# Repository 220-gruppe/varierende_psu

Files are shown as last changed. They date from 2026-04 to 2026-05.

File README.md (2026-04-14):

Standalone

This is part of the “Projekt SMPS.”

The project is developed using PlatformIO as the framework.

The standalone folder is specifically intended for testing individual components and ongoing development.

There will also be a main PlatformIO project folder. This folder will contain the fully integrated code for the final solution. Each individual component will be placed in its own file, including the functions and behavior required to handle that element—either independently, in coordination with other modules, or within the main program.

A key design decision is whether modules should be implemented as individual classes (allowing state to be managed and modified) or as function-based implementations without maintaining state.

# Working with Hardware 🛠️
To work with hardware e.g schematics and pcb designs you need git LFS and Kicad

### git lfs 
To install git lfs run
```
git lfs install
```
**This must be run** it prevents committing unlocked files which can cause accidental overwrites
```
git config lfs.locksverify true
```

### Kicad
Install via website
## Daily workflow
#### 1. Before editing
Before editing a PCB or schematic run:
```
git lfs locks
```
This allows you to see the files that are locked. \
If the files are unlocked, lock them.\
An example:
```
git lfs lock hardware/buck-converter/buck-converter.sch
```
#### 2. Working
Open the files, edit and commit.
Commit example
```
git add hardware/my_project.kicad_pcb
git commit -m "Route motor driver power stage"
git push
```

#### 3. IMPORTANT - unlock when finished🔓
Unlock when finished editing and commiting, so that others can work on the files
Example:
```
git lfs unlock hardware/buck-converter/buck-converter.sch
```
You can also use the "ID" the lock has from the git lfs locks output.

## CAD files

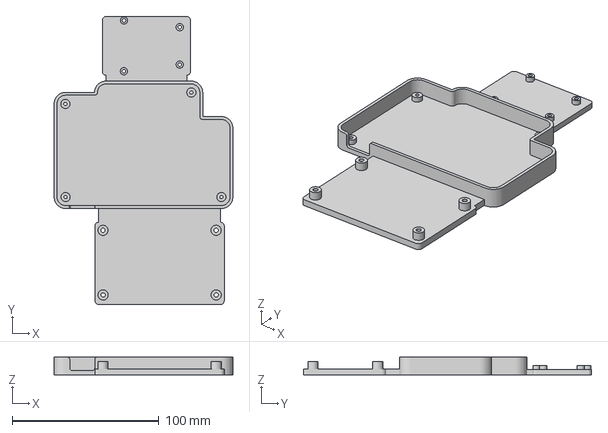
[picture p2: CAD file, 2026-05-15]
hardware/buck-converter/3D print/SMPS case+attachments.3mf
121.7 x 196.0 x 12.0 mm

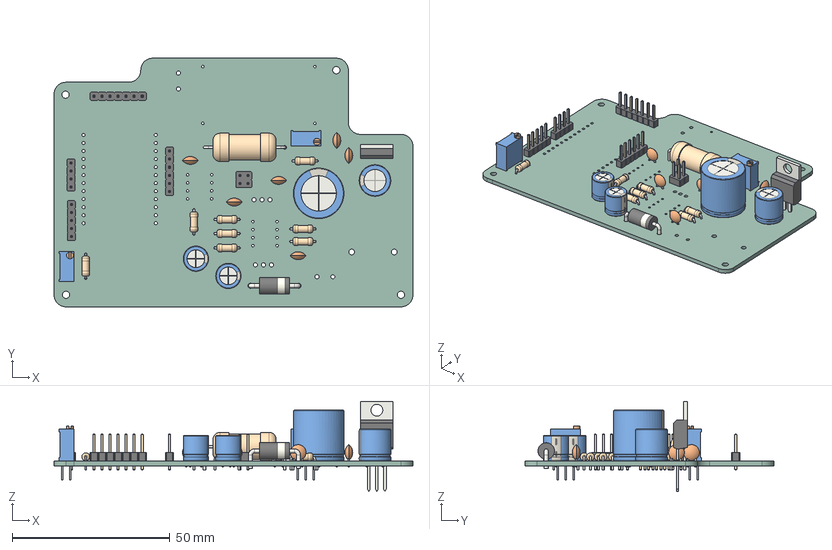
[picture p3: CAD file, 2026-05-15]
hardware/buck-converter/Board.step
113.7 x 78.7 x 28.5 mm
C_Disc_D5.0mm_W2.5mm_P2.50mm x 6
CP_Radial_D8.0mm_P3.50mm x 2
R_Axial_DIN0207_L6.3mm_D2.5mm_P7.62mm_Horizontal x 8
CP_Radial_D10.0mm_P5.00mm
PinHeader_1x05_P2.54mm_Vertical
R_Axial_DIN0922_L20.0mm_D9.0mm_P25.40mm_Horizontal
PinHeader_1x07_P2.54mm_Vertical
PinHeader_2x02_P2.54mm_Vertical
PinHeader_1x06_P2.54mm_Vertical
D_DO-201AD_P15.24mm_Horizontal
Potentiometer_Bourns_3296Y_Vertical x 2
CP_Radial_D16.0mm_P7.50mm
TO-220-3_Vertical
PinHeader_1x04_P2.54mm_Vertical
buck-converter_PCB

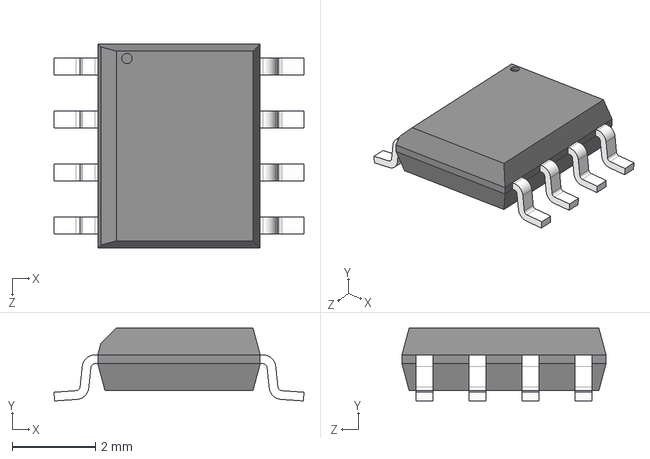
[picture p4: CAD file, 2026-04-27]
hardware/components/AD620/AD620.step
6.00 x 1.75 x 4.90 mm

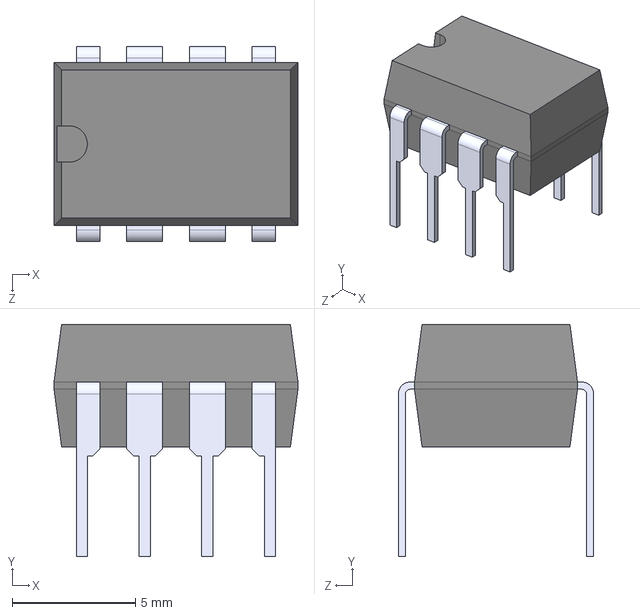
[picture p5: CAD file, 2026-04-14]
hardware/components/IR2104/IR2104.step
9.88 x 9.40 x 7.91 mm

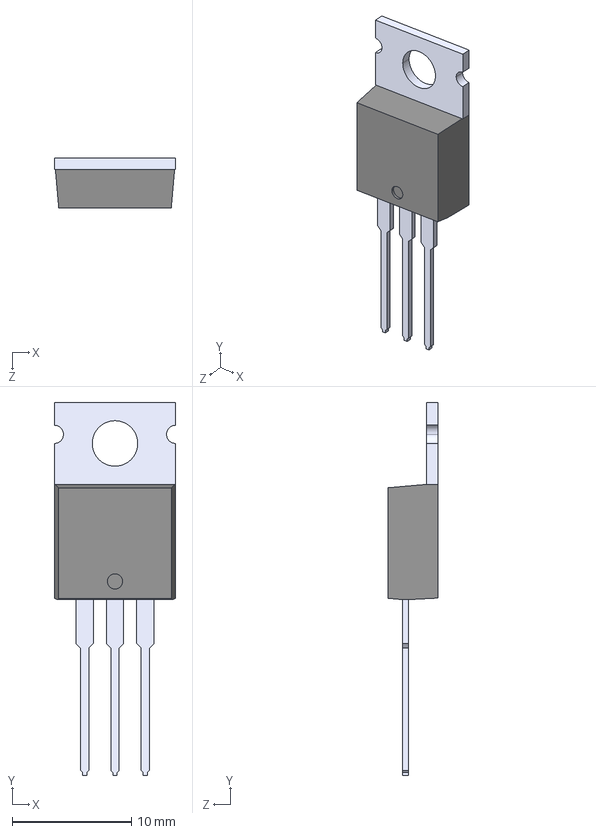
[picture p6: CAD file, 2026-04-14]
hardware/components/IRF2807ZPBF/IRF2807ZPBF.step
10.2 x 31.2 x 4.19 mm

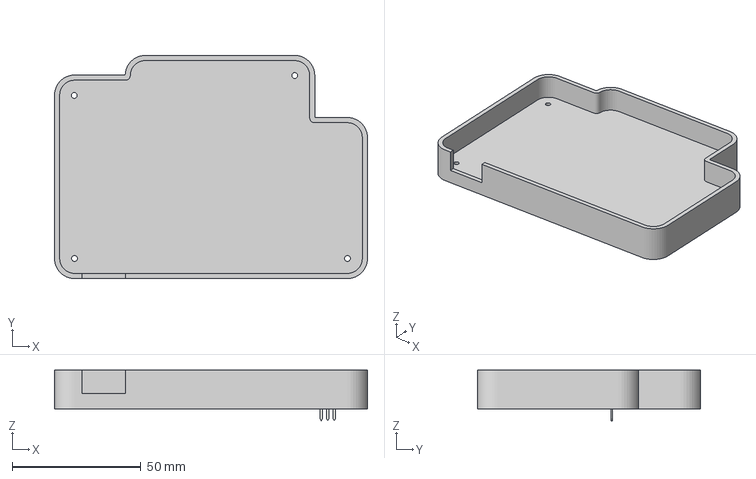
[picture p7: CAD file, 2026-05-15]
hardware/buck-converter/3D print/SMPS case.3mf
121.7 x 86.7 x 19.7 mm

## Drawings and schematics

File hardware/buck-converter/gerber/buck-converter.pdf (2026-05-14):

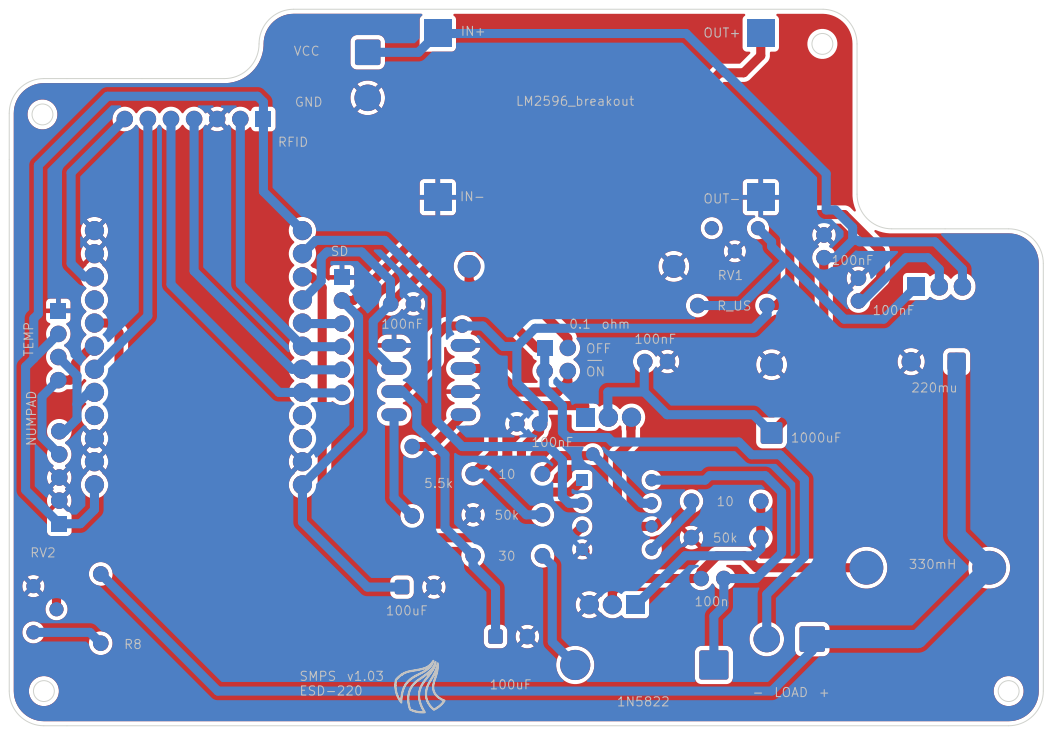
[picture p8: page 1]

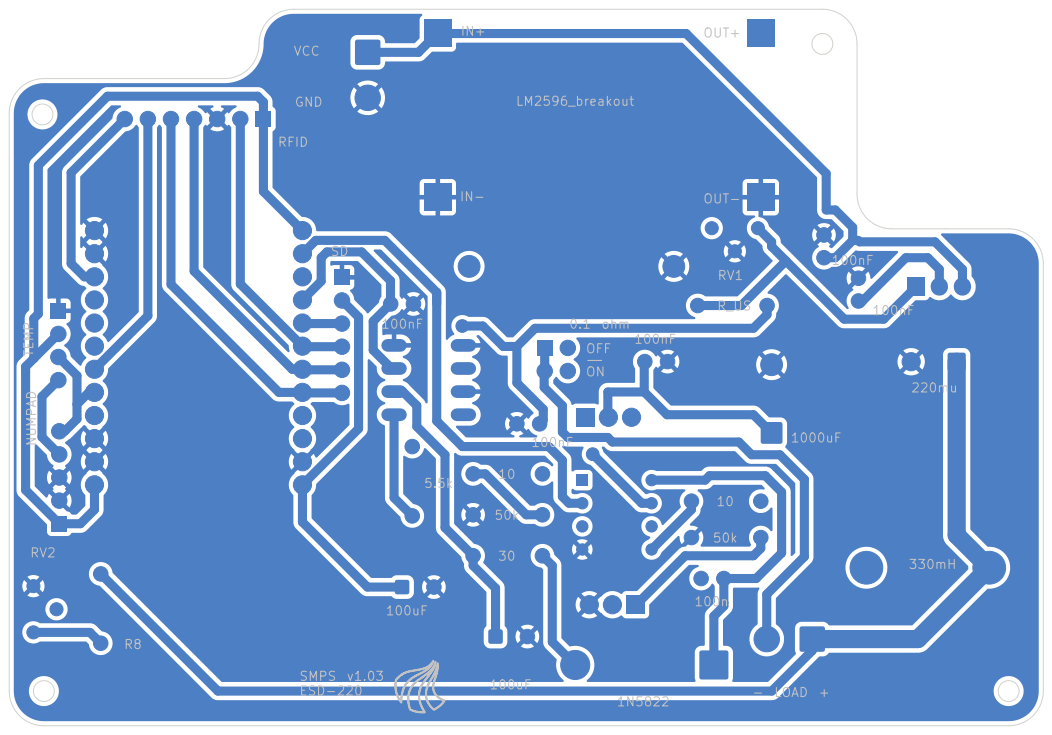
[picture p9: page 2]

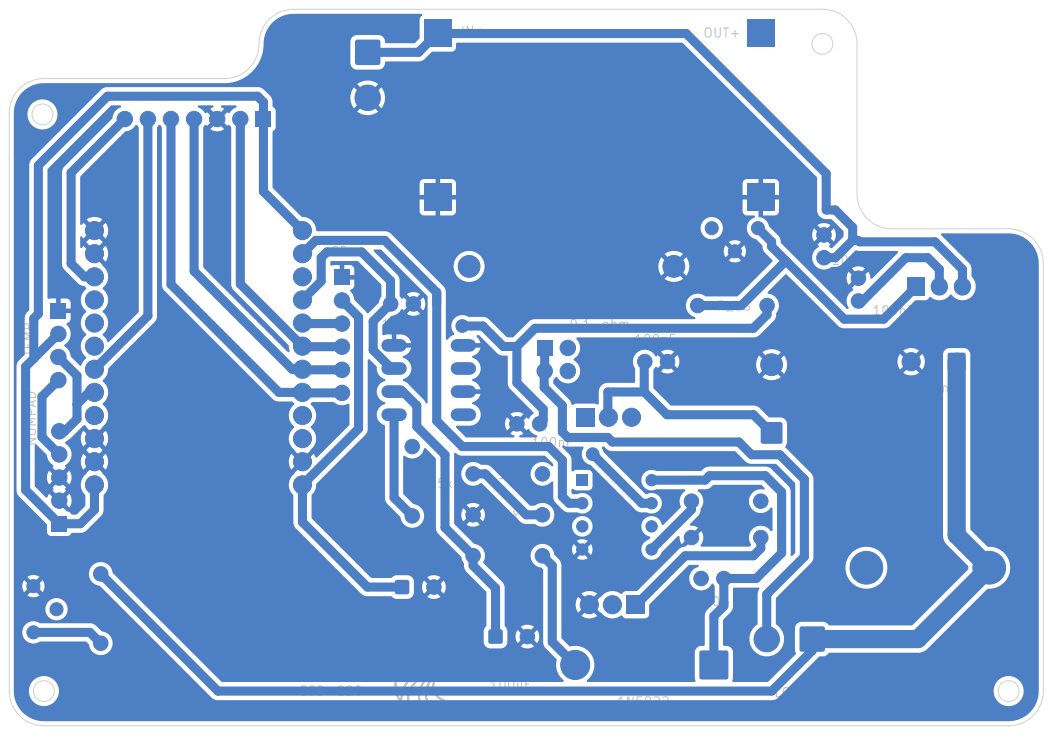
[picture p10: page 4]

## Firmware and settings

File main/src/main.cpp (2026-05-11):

// freeRTOS
#include <freertos/FreeRTOS.h>
#include <freertos/task.h>
#include <SPI.h>
#include <Wire.h>

// Include
#include "database.h"
#include "interface_state.h"
#include "server.h"
#include "pwm.h"
#include "auth.h"
#include "rfid.h"
#include "numpad.h"
#include "screen.h"
#include "tempsensor.h"
#include "programs.h"

// SPI
#define SPI_MISO 11
#define SPI_MOSI 13
#define SPI_SCK 12

// I2C
#define I2C_SDA1 21
#define I2C_SCL1 16
#define I2C_SDA2 17
#define I2C_SCL2 18

float heatInput = 70000; // aendres til noget fra sensor
float targetCurrentMA = 5.0;
float Kp = 1.1;

TaskHandle_t auth_interfaceT = nullptr;
// TaskHandle_t user_interfaceT = nullptr;
TaskHandle_t serverT = nullptr;
TaskHandle_t pwmT = nullptr;

void pwmTask(void *pvParameters)
{
  TickType_t lastWake = xTaskGetTickCount();

  for (;;)
  {
    pwmControlStep(targetCurrentMA, Kp);
    xTaskDelayUntil(&lastWake, pdMS_TO_TICKS(10));
  }
}

void auth_interfaceTask(void *pvParameters)
{
  TickType_t lastWake = xTaskGetTickCount();

  for (;;)
  {
    processAuthenticationInterfaceState();
    processUserInterfaceState();
    drawScreen();
    xTaskDelayUntil(&lastWake, pdMS_TO_TICKS(10));
  }
}

/*
void user_interfaceTask(void *pvParameters)
{
  TickType_t lastWake = xTaskGetTickCount();

  for (;;)
  {
    processUserInterfaceState();
    xTaskDelayUntil(&lastWake, pdMS_TO_TICKS(10));
  }
}
*/

void serverTask(void *pvParameters)
{
  TickType_t lastWake = xTaskGetTickCount();

  for (;;)
  {
    processServer();
    xTaskDelayUntil(&lastWake, pdMS_TO_TICKS(10));
  }
}

void setup()
{
  Serial.begin(115200);
  delay(3000);
  Serial.println("Boot startet");

  // Start SPI
  SPI.begin(SPI_SCK, SPI_MISO, SPI_MOSI);

  // 1ST I2C BUS (NUMPAD)
  Wire.begin(I2C_SDA1, I2C_SCL1);

  // 2ND I2C BUS (TEMPSSENSOR)
  Wire1.begin(I2C_SDA2, I2C_SCL2);

  setupDatabase();
  setupAuth();
  setupPwm();
  setupRFID();
  setupTempSensor();
  setupNumpad();
  setupScreen();
  setupServer();

  Serial.println("Starter tasks");

  // xTaskCreatePinnedToCore(pwmTask, "pwm", 2048, NULL, 3, &pwmT, 1);
  xTaskCreatePinnedToCore(auth_interfaceTask, "auth_interface", 16384, NULL, 2, &auth_interfaceT, 1);
  // xTaskCreatePinnedToCore(user_interfaceTask, "user_interface", 8192, NULL, 1, &user_interfaceT, 1);
  xTaskCreatePinnedToCore(serverTask, "server", 6144, NULL, 1, &serverT, 0);

  /*==============================================================*/
  // DEBUGGING
  if (auth_interfaceT == nullptr)
    Serial.println("auth_interfaceT FEJL - kunne ikke oprettes");
  else
    Serial.println("auth_interfaceT OK");

  // if (user_interfaceT == nullptr)
  //   Serial.println("user_interfaceT FEJL - kunne ikke oprettes");
  // else
  //   Serial.println("user_interfaceT OK");

  if (serverT == nullptr)
    Serial.println("serverTask FEJL - kunne ikke oprettes");
  else
    Serial.println("serverTask OK");
  /*==============================================================*/

  DB("users", "UID,USER,PASSWORD");
  databaseRead();
}

void loop()
{
  vTaskDelay(pdMS_TO_TICKS(1000));
}

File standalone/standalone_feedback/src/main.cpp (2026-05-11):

#include <Arduino.h>

const int pwmPin = 12;
const int shutdown = 11;
const int shuntPin = 13;
const int freq = 50000;
const int ledChannel = 0;
const int resolution = 9;

// Regulator variabler
float targetCurrentMA = 1500.0; // ønsket strøm
float currentDuty = 255.0;
float Kp = 0.1; // styrke

void setup()
{
  Serial.begin(115200);
  pinMode(shutdown, OUTPUT);
  delay(10);
  digitalWrite(shutdown, HIGH);
  
  ledcSetup(ledChannel, freq, resolution);
  ledcAttachPin(pwmPin, ledChannel);
  
  analogSetAttenuation(ADC_0db);
}

void loop()
{
  long sum = 0;
  for (int i = 0; i < 50; i++)
  {
    sum += analogRead(shuntPin);
  }
  float adcAvg = sum / 50.0;

  float voltage = (adcAvg / 4095.0) * 1.1;
  float currentMA = (voltage / 0.1055) * 1000.0; 

  float fejl = targetCurrentMA - currentMA;
  currentDuty += fejl * Kp;

  if (currentDuty > 511) currentDuty = 511;
  if (currentDuty < 0) currentDuty = 0;

  ledcWrite(ledChannel, (int)currentDuty);


  Serial.print("ADC: ");
  Serial.print(adcAvg, 0);
  Serial.print(" | Current: ");
  Serial.print(currentMA);
  Serial.print("mA | PWM Duty: ");
  Serial.print((currentDuty / 511.0) * 100);
  Serial.println("%");

  delay(20);
}

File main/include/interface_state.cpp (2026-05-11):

#include "interface_state.h"

#include <Arduino.h>

#include "auth.h"
#include "numpad.h"
#include "rfid.h"
#include "screen.h"
#include "programs.h"
#include "tempsensor.h"
#include "svejse_logs.h"

namespace
{
    enum class UserInterfaceState
    {
        Idle,
        Measure,
        Menu,
        Svejse,
        Result,
        Data,
        Log,
        Choice
    };

    constexpr unsigned long INACTIVITY_TIMEOUT_MS = 240000;
    constexpr unsigned long TEMP_DISPLAY_MS = 3000;
    unsigned long stateTimer = 0;

    UserInterfaceState currentUserInterfaceState = UserInterfaceState::Idle;

    bool UserInterfaceNumpadOverride(int activeBit)
    {
        resetAuthTimer();
        Serial.println("NUMPAD IS OVERRIDDEN YO" + String(activeBit));
        switch (currentUserInterfaceState)
        {
        case UserInterfaceState::Idle:
            if (activeBit == 3)
            {
                currentUserInterfaceState = UserInterfaceState::Measure;
                setScreenState(ScreenState::Measuring);
                return true;
            }
            break;
        case UserInterfaceState::Menu:
            if (activeBit == 7)
            {
                cycleProgram();
                forceRedraw();
                return true;
            }
            if (activeBit == 11)
            {
                if (confirmProgram())
                {
                    showTemporaryScreen(ScreenState::ProgramConfirmation);
                    startSvejse();
                    currentUserInterfaceState = UserInterfaceState::Svejse;
                }
                return true;
            }
            if (activeBit == 3)
            {
                currentUserInterfaceState = UserInterfaceState::Idle;
                return true;
            }
            break;
        case UserInterfaceState::Result:
            if (activeBit == 11)
            {
                startSvejse();
                currentUserInterfaceState = UserInterfaceState::Svejse;
                return true;
            }
            if (activeBit == 0)
            {
                currentUserInterfaceState = UserInterfaceState::Data;
                return true;
            }
            break;
        case UserInterfaceState::Data:
            if (activeBit == 11)
            {
                currentUserInterfaceState = UserInterfaceState::Log;
                return true;
            }
            break;
        case UserInterfaceState::Choice:
            if (activeBit == 3)
            {
                currentUserInterfaceState = UserInterfaceState::Idle;
                return true;
            }
            if (activeBit == 0)
            {
                logout();
                resetNumpad();
                currentUserInterfaceState = UserInterfaceState::Idle;
                selectedProgram = 0;
                setScreenState(ScreenState::Ready);
                return true;
            }
            break;
        default:
            break;
        }
        return false;
    }

    void showUnknownChip()
    {
        setScreenState(ScreenState::Ready);
        showTemporaryScreen(ScreenState::UnknownChip);
    }

    void handleInactivity()
    {
        if (!authTimedOut(INACTIVITY_TIMEOUT_MS))
        {
            return;
        }

        logout();
        resetNumpad();
        setScreenState(ScreenState::Ready);
        showTemporaryScreen(ScreenState::InactiveLogout);
        Serial.println("logget ud pga inaktivitet");
    }

    void handleWaitingForChipState(const String &scannedUID)
    {
        setScreenState(ScreenState::ScanNewChip);

        if (scannedUID.length() == 0)
        {
            return;
        }

        if (completePendingUserCreation(scannedUID))
        {
            resetNumpad();
            setScreenState(ScreenState::Ready);
            Serial.println("Ny bruger oprettet");
            return;
        }

        showUnknownChip();
    }

    void handleWaitingForPinState()
    {
        setScreenState(ScreenState::EnterPin);
        numpadLogik();

        if (!isUserDone())
        {
            return;
        }

        if (authUser(getTyped()))
        {
            setScreenState(ScreenState::LoggedIn);
            setNumpadOverride(UserInterfaceNumpadOverride);
            resetNumpad();
            Serial.println("ADGANG GODKENDT");
            return;
        }

        setScreenState(ScreenState::EnterPin);
        showTemporaryScreen(ScreenState::WrongPin);
        resetNumpad();
        Serial.println("FORKERT KODE!");
    }

    void handleLoggedInState()
    {
        handleInactivity();
    }

    void handleReadyState(const String &scannedUID)
    {
        if (scannedUID.length() == 0)
        {
            setScreenState(ScreenState::Ready);
            return;
        }

        if (loadUserByUID(scannedUID))
        {
            resetNumpad();
            setScreenState(ScreenState::EnterPin);
            return;
        }

        showUnknownChip();
    }

    void handleIdleState()
    {
        setScreenState(ScreenState::Idle);
        Serial.println("CALLING NUMPADLOGIK");
        numpadLogik();
    }

    void handleMeasureState()
    {
        resetAuthTimer();

        if (stateTimer == 0)
        {
            setScreenState(ScreenState::Measuring);
            AVG_TEMP = takeTempMeasurement();
            setScreenState(ScreenState::MeasurementResult);
            stateTimer = millis();
            return;
        }

        if (millis() - stateTimer >= TEMP_DISPLAY_MS)
        {
            stateTimer = 0;
            selectedProgram = 1;
            Serial.println("GOING TO MENU");
            currentUserInterfaceState = UserInterfaceState::Menu;
        }
    }

    void handleMenuState()
    {
        Serial.println("IN MENU STATE");
        setScreenState(ScreenState::ProgramSelection);
        numpadLogik();
    }

    void handleSvejseState()
    {
        unsigned long elapsed = millis() - svejseStartTime;
        unsigned long remaining = (elapsed < svejseDuration) ? (svejseDuration - elapsed) : 0;
        setRemainingTime(remaining);
        setScreenState(ScreenState::SvejseActive);

        if (svejseHandler())
        {
        Serial.println("svejseHandler returned true");
        stopSvejse();
        Serial.println("stopSvejse done");
        heatInput = calculatedOutputEnergy();
        Serial.println("calculatedOutputEnergy done");
        saveSvejsningResult();
        Serial.println("saveSvejsningResult done");
        currentUserInterfaceState = UserInterfaceState::Result;
        Serial.println("Transitioning to Result");
        }
    }
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

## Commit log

2026-04-02 Login, Logud, hotspot fixed
    [main.cpp]
2026-04-13 Inaktivitets timer oprettet, kode opryddet eller noget
2026-04-14 Tilføjet flowchart
2026-04-14 add hardware folder structer, add LFS support via .gitattribues, add LFS guide to README, edit .gitignore to ignore Kicad trash files
    [IR2104.step, IRF2807ZPBF.step, buck-converter.kicad_pcb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]
2026-04-14 Test-kode til at teste ESP ADC målingshastighed
2026-04-14 add footprints to pcb
    [buck-converter.kicad_pcb, buck-converter.kicad_sch]
2026-04-21 written software to RTOS and added pwm in main progam
2026-04-22 tilføjet altium pcb
    [buck-converter-altium.PcbDoc, buck-converter-altium.PrjPcb, buck-converter-altium.SchDoc]
2026-04-22 Footprints for inductor and resistors, small work in PCB
    [buck-converter.kicad_pcb, buck-converter.kicad_sch]
2026-04-23 Afkoblingskondensator på VCC gate driver
    [buck-converter.kicad_sch]
2026-04-23 Rykket lidt rundt
    [buck-converter.kicad_pcb]
2026-04-24 Tilføjede kondensatorer på drain
    [buck-converter.kicad_sch]
2026-04-26 Added symbol and footprint for ESP32
    [buck-converter.kicad_pcb, buck-converter.kicad_sch]
2026-04-26 Small changes to PCB placements
    [buck-converter.kicad_pcb]
2026-04-27 Work on PCB and footprints
    [buck-converter.kicad_pcb, buck-converter.kicad_sch]
2026-04-27 Fixer merge
    [buck-converter.kicad_pcb]
2026-04-27 Fixed libraries footprints and schematic
    [buck-converter.kicad_pcb, buck-converter.kicad_sch]
2026-04-27 Added LM2596_breakout, fixed wires
    [buck-converter.kicad_pcb, buck-converter.kicad_sch]
2026-04-28 Fixed libs, actually this time
    [buck-converter.kicad_pcb, buck-converter.kicad_sch]
2026-04-28 Ground plane, PCB, mounting holes
    [buck-converter.kicad_pcb, buck-converter.kicad_sch]
2026-04-28 Fixed libs paths
    [buck-converter.kicad_pcb]
2026-04-28 Added gerberfiles
    [buck-converter-B_Cu.gbl, buck-converter-B_Silkscreen.gbo, buck-converter-Edge_Cuts.gm1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]
2026-04-28 2.54mm headers, inductor footprint to match, re-trace GPIO
    [buck-converter.kicad_pcb, buck-converter.kicad_sch]
2026-04-29 Drill, gerber and silkscreen added
    [buck-converter-B_Cu.gbl, buck-converter-B_Silkscreen.gbo, buck-converter-Edge_Cuts.gm1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]
2026-04-29 Arbejde på 3A traces
    [buck-converter.kicad_pcb, buck-converter_v2.kicad_pcb]
2026-04-30 Rerouted traces for 3A
    [buck-converter.kicad_pcb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]
2026-04-30 refactor framework
2026-04-30 refactor framework for statefull code
2026-05-02 Fixed floating VCC, vs to ground issue, and added new proper silkscreen
    [buck-converter.kicad_pcb]
2026-05-04 Changed SCL pin
    [buck-converter.kicad_pcb, buck-converter.kicad_sch]
2026-05-05 Voltage divider
    [buck-converter.kicad_pcb, buck-converter.kicad_sch]
2026-05-05 Added voltage divider for measuring, fixed traces
    [buck-converter.kicad_pcb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]
2026-05-05 Changed LM2596 footprint to match
2026-05-08 Trace width og silk screen
    [buck-converter.kicad_pcb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]
2026-05-11 Ændrer 12v til 20v
    [buck-converter.kicad_sch]
2026-05-11 Fixer merge conflict
    [buck-converter.kicad_pcb]
2026-05-12 Update ADC-målinger
    Inkludere kode til at starte PWM signal og måle inden for den tid
2026-05-15 3D print filer
    [Board.step, SMPS case+attachments.3mf, SMPS case.3mf]
